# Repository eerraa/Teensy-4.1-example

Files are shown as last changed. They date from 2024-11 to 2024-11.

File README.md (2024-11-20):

# Teensy 4.1 Kicad example project
Kicad files to make a custom Teensy 4.1, based on the official Teensy schematics, but exposing all pins for testing. All the 55 pins except D41 are brought out for testing. I'm using a USB Type C receptacle rather than USB Micro / A connectors. Don't forget that you'll need to buy the MKL02Z32VFG4 from PJRC for this to work. Also - be sure to scroll down on the MKL02Z32VFG4 page. There are [lots of important information there](https://www.pjrc.com/store/ic_mkl02_t4.html) on power sequencing and layout.

## Know bugs
This version is tested and works, but the MAX1562 that I used for the USB switch has inverted polarity from what is expected. You can get around this by using the alternate part MAX1563, or something else. Only reason I went with this 4A chip is the parts shortage.

I just removed the chip and soldered bodge-wires to bypass it. This also works, but I guess it then lacks protection. I've tested with keyboard & mouse.

## Features

The board includes the required parts

- MIMXRT1062DVJ6B (Arm Cortex M7 @ 600 Mhz)
- MKL02Z32VFG4 (must be purchased from PJRC)
- W25Q64JVXGIM (8Mb spi Flash)

Optional parts (not in PJRC's design)

- [USB Type C](https://github.com/jenschr/USB-C-Connectors) for power & debug
- USB Type C host port with MAX1562 for power control
- 2.54mm pin header connections for all pins but D41
- JTAG pins broken out (not tested, but there)

Not included (from PJRC's design)
- Extra SpiFlash or PSRAM
- Ethernet

Note: the schematic symbol for the IMXRT1062 chip is really clumsy and makes the schematic more complex than required, but that's what you get if you use SamacSys Library Loader rather than making the symbol yourself.

## Picture
Here's a picture of the boards when I soldered them:



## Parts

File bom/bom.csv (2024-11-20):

Designator | Footprint | Quantity | Value | LCSC Part #
C1, C10, C13, C17, C2, C22, C23, C25, C4, C8 | 603 | 10 | 0.22uf | C21120
C11, C18, C9 | 805 | 3 | 10uf | C15850
C12, C19, C24, C26, C6 | 603 | 5 | 4.7uf | C19666
C14, C15 | 603 | 2 | 10pf | C1634
C16, C21 | 603 | 2 | 9pf | C430713
C20, C5 | 603 | 2 | 10nf | C57112
C3, C7 | 603 | 2 | 2.2uf | C23630
D1 | SOT-143 | 1 | SP0503BAHT | C7074
D2, D4 | 402 | 2 | LED | C20613596
D3 | SOT-23 | 1 | BAT54C | C37704
F1 | 805 | 1 | Fuse | C5220829
FB1, FB2 | 805 | 2 | Ferrite_Bead | C454098
IC1 | BGA196C80P14X14_1200X1200X152 | 1 | MIMXRT1062DVJ6B | C3216699
J1, J2 | Hirose_FH12-20S-0.5SH_1x20-1MP_P0.50mm_Horizontal | 2 | Conn_01x20 | C596730
J3 | PinHeader_1x03_P2.54mm_Vertical | 1 | Conn_01x03_Male
L1 | 805 | 1 | 4.7uH | C86090
NCP1 | DFN-6-1EP_3x3mm_P0.95mm_EP1.7x2.6mm | 1 | OnSemi NCP692, fixed version | C145519
PROG1 | KMR241GLFS | 1 | SW_Push | C221682
Q1 | SOT-23 | 1 | Q_PMOS_GDS_DMP3125L | C459542
R1, R2 | 603 | 2 | 5.1k | C23186
R3, R4, R9 | 603 | 3 | 100k | C25803
R5 | 603 | 1 | 1M | C22935
R6, R8 | 402 | 2 | 1k | C11702
R7 | 603 | 1 | 2.2M | C22938
SWD1 | PinHeader_1x07_P1.27mm_Vertical | 1 | SWD
TP1, TP2, TP3, TP4, TP5, TP6, TP7 | TestPoint_Pad_D1.0mm | 7 | TestPoint
U1 | XSON8_4x4mm | 1 | W25Q64JVXGIM
U2 | QFN-16-1EP_3x3mm_P0.5mm_EP1.8x1.8mm | 1 | MKL02Z32VFG4
USB_UFP1 | USB_C_Receptacle_Hroparts_TYPE-C-31-M-12 | 1 | USB_C_Receptacle_USB2.0 | C165948
Y1 | Crystal_SMD_Abracon_ABM3B-4Pin_5.0x3.2mm | 1 | Crystal_GND23 | C112587
Y2 | Crystal_SMD_2012-2Pin_2.0x1.2mm | 1 | Crystal | C510776

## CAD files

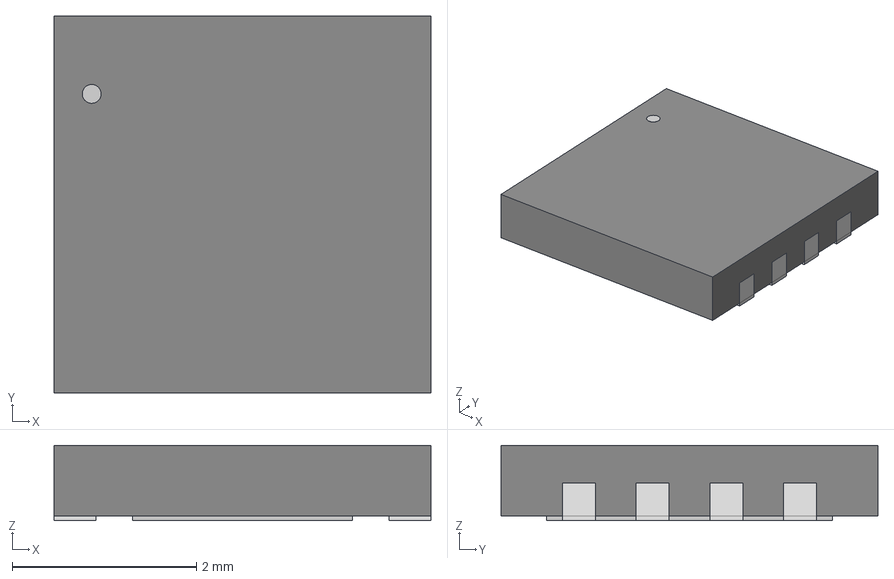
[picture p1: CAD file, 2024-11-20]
3d/DFN_XGIQTR_WIN.step
4.09 x 4.09 x 0.815 mm

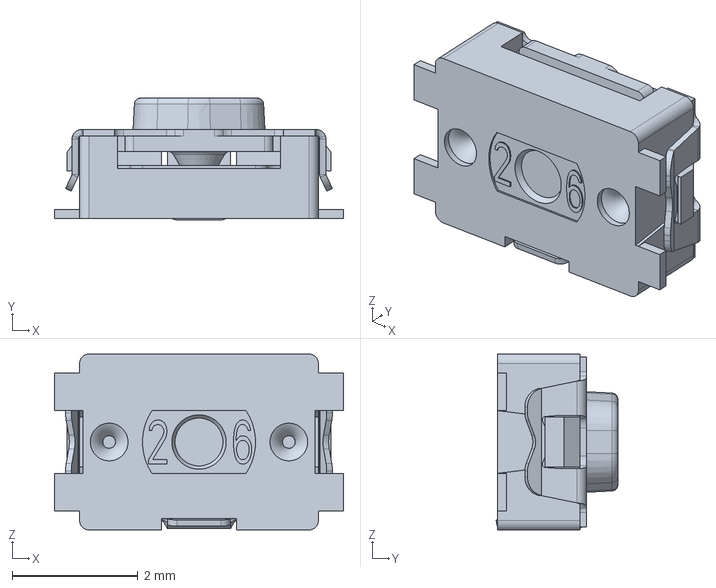
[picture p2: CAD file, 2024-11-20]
3d/KMR241GLFS.stp
4.60 x 1.94 x 2.80 mm

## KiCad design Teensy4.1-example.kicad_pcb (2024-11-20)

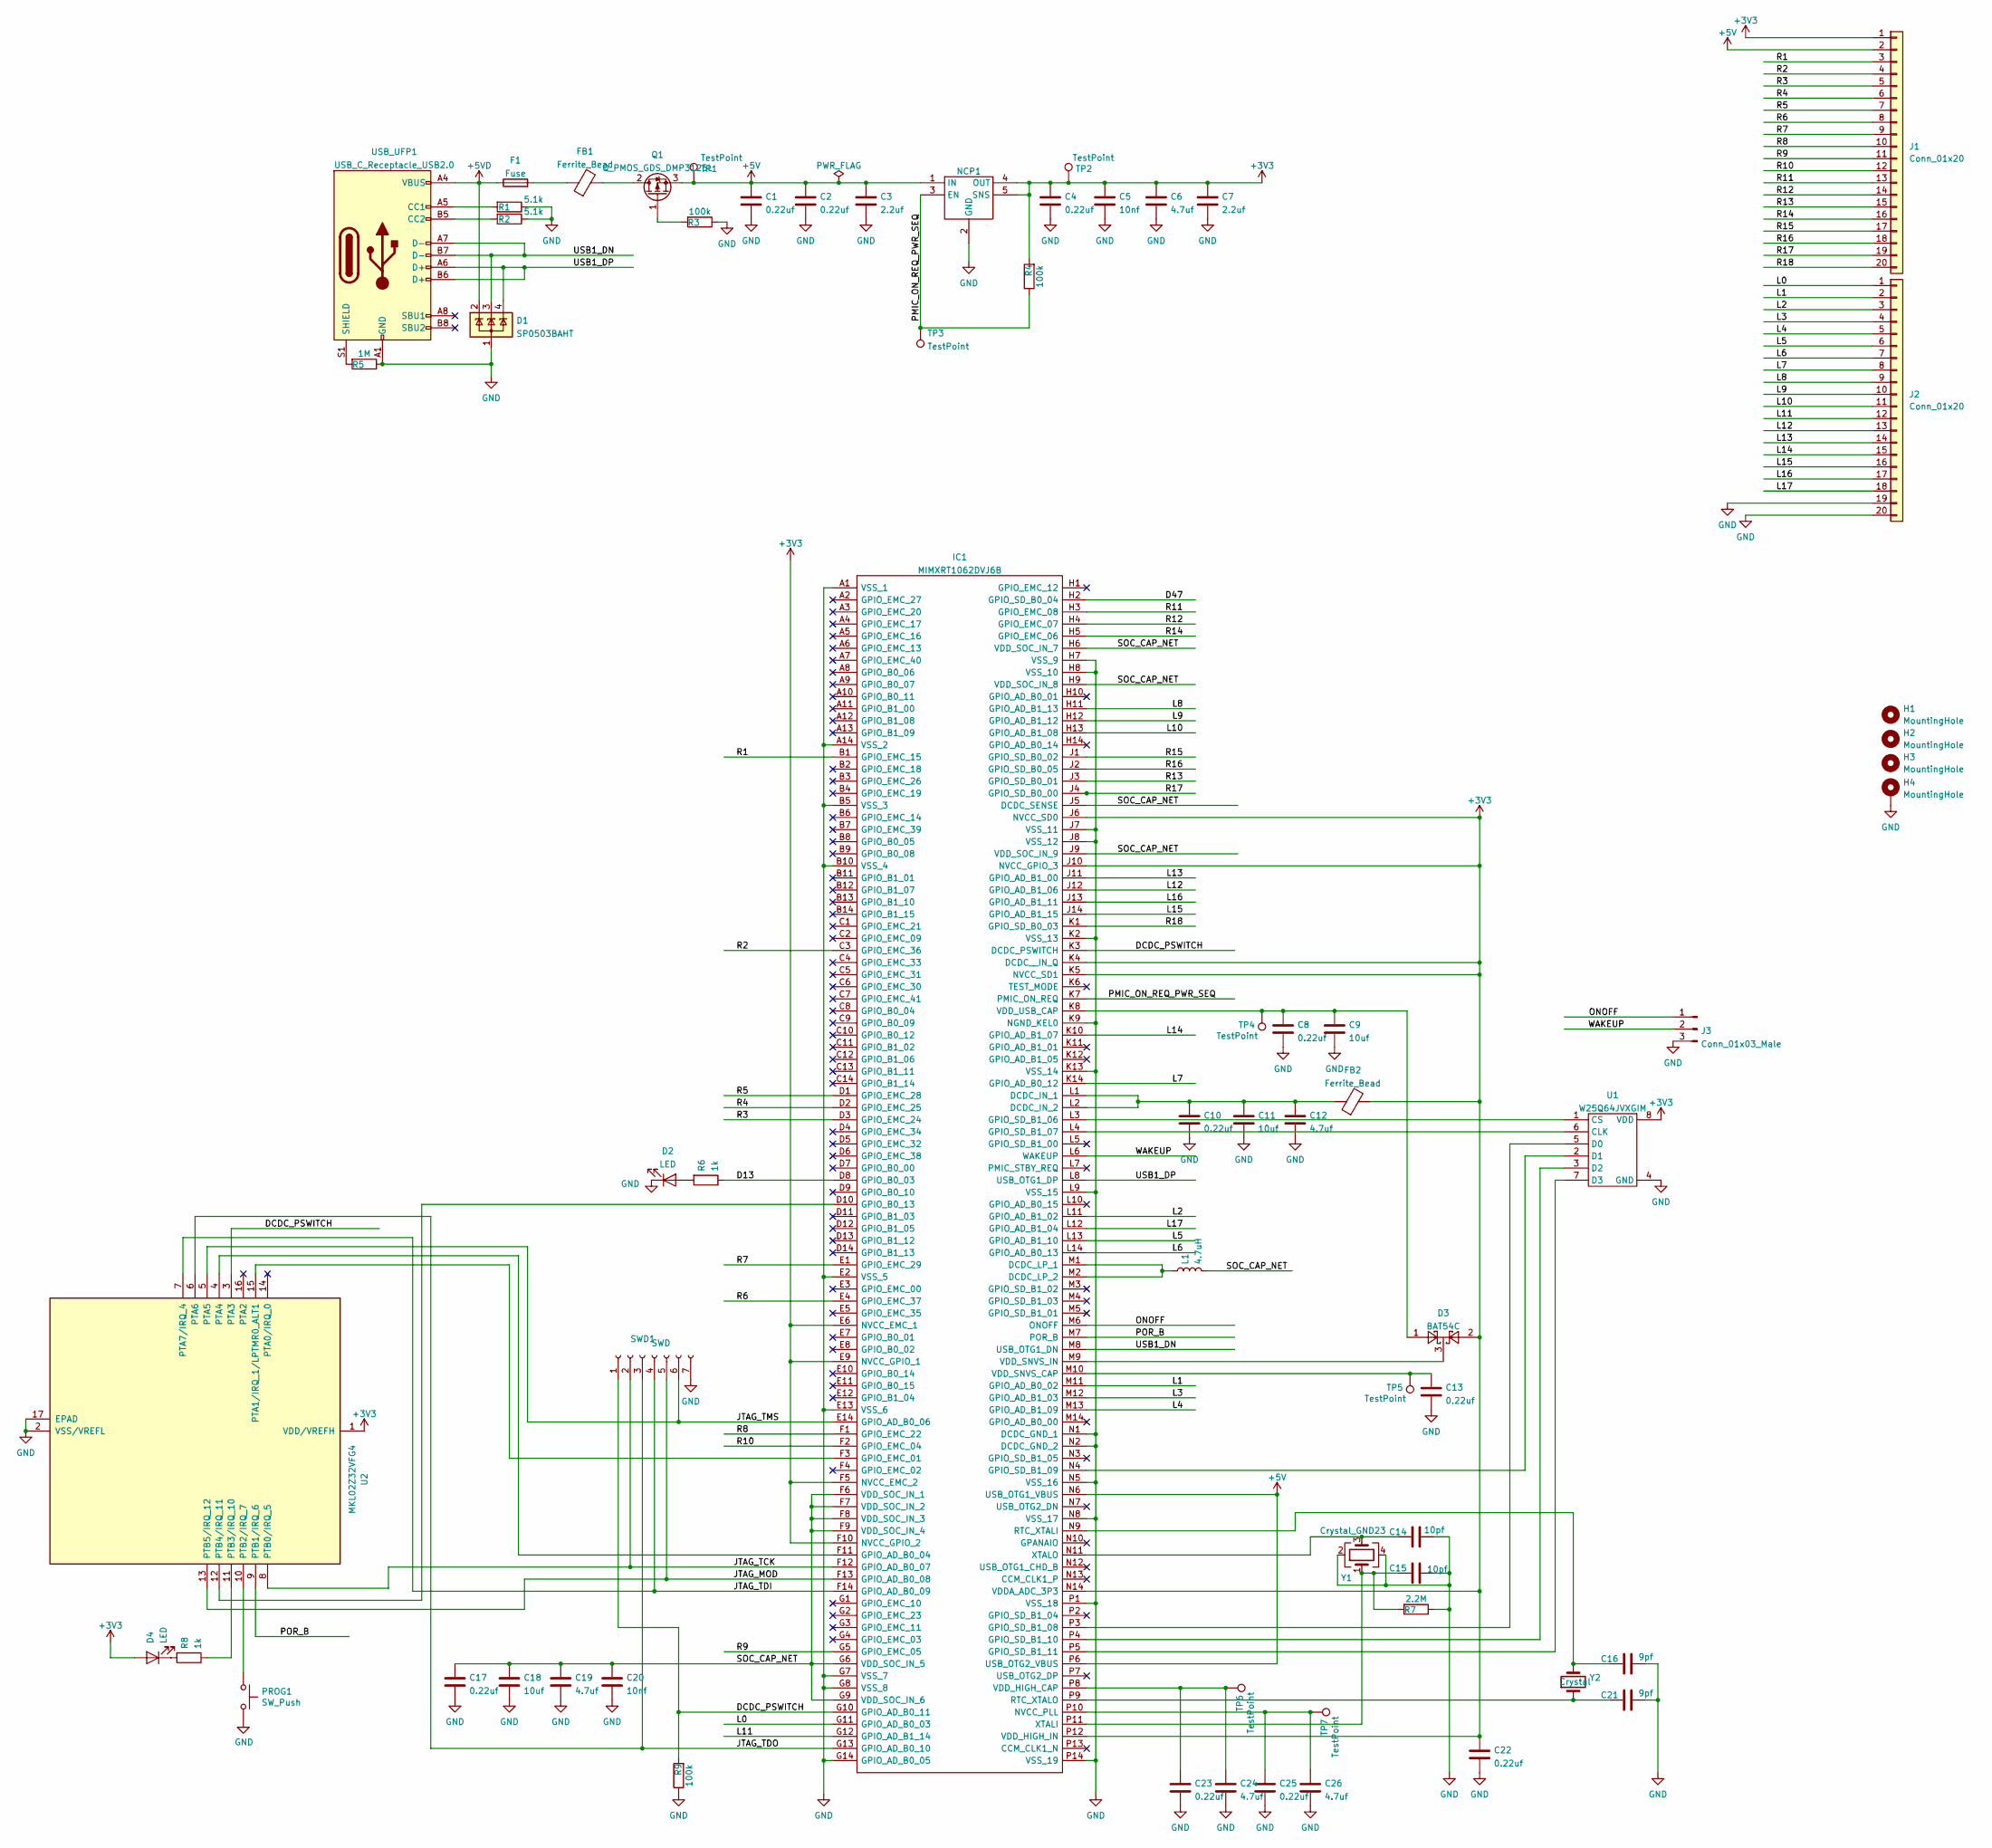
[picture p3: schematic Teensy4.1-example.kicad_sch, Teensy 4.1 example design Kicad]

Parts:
C1, C2, C4, C8, C10, C13, C17, C22, C23, C25: 0.22uf; C_0603_1608Metric; MPN CC0603KRX7R6BB224
C3, C7: 2.2uf; C_0603_1608Metric; MPN CL10B225KP8NNNC
C5, C20: 10nf; C_0603_1608Metric; MPN 0603B103K160CT
C6, C12, C19, C24, C26: 4.7uf; C_0603_1608Metric; MPN CL10B475KQ8NQNC
C9, C11, C18: 10uf; C_0805_2012Metric; MPN GRM21BR71A106KA73K
C14, C15: 10pf; C_0603_1608Metric; MPN CC0603KRX7R6BB224
C16, C21: 9pf; C_0603_1608Metric; MPN GRM1885C1H9R0DA01D
D1: SP0503BAHT; SOT-143
D2, D4: LED; LED_0402_1005Metric
D3: BAT54C; SOT-23
F1: Fuse; R_0805_2012Metric; MPN 0ZCK0050FF2E
FB1, FB2: Ferrite_Bead; R_0805_2012Metric; MPN FBMH2012HM121-T‎
H1, H2, H3, H4: MountingHole; MountingHole_2.7mm_M2.5_DIN965_Pad_TopBottom
IC1: MIMXRT1062DVJ6B; BGA196C80P14X14_1200X1200X152; Mouser Part Number 771-MIMXRT1062DVJ6B
J1, J2: Conn_01x20; Hirose_FH12-20S-0.5SH_1x20-1MP_P0.50mm_Horizontal
J3: Conn_01x03_Male; PinHeader_1x03_P2.54mm_Vertical
L1: 4.7uH; C_0805_2012Metric; MPN LQM21PN4R7MGRD
NCP1: OnSemi NCP692, fixed version; DFN-6-1EP_3x3mm_P0.95mm_EP1.7x2.6mm; MPN NCP692MN33T2G
PROG1: SW_Push; KMR241GLFS; MPN KMR241GLFS
Q1: Q_PMOS_GDS_DMP3125L; SOT-23
R1, R2: 5.1k; R_0603_1608Metric; MPN RC0603FR-075K1L
R3, R4, R9: 100k; R_0603_1608Metric
R5: 1M; R_0603_1608Metric
R6, R8: 1k; R_0402_1005Metric
R7: 2.2M; R_0603_1608Metric
SWD1: SWD; PinHeader_1x07_P1.27mm_Vertical
TP1, TP2, TP3, TP4, TP5, TP6, TP7: TestPoint; TestPoint_Pad_D1.0mm
U1: W25Q64JVXGIM; XSON8_4x4mm
U2: MKL02Z32VFG4; QFN-16-1EP_3x3mm_P0.5mm_EP1.8x1.8mm; MPN Custom firmware part
USB_UFP1: USB_C_Receptacle_USB2.0; USB_C_Receptacle_Hroparts_TYPE-C-31-M-12
Y1: Crystal_GND23; Crystal_SMD_Abracon_ABM3B-4Pin_5.0x3.2mm
Y2: Crystal; Crystal_SMD_2012-2Pin_2.0x1.2mm; MPN ABS06-32.768KHZ-9-1-T

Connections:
+3V3: C4.1, C5.1, C6.1, C7.1, C22.1, D3.2, D4.2 (A), FB2.2, IC1.E6 (NVCC_EMC_1), IC1.E9 (NVCC_GPIO_1), IC1.F5 (NVCC_EMC_2), IC1.F10 (NVCC_GPIO_2), IC1.J6 (NVCC_SD0), IC1.J10 (NVCC_GPIO_3), IC1.K4 (DCDC__IN_Q), IC1.K5 (NVCC_SD1), IC1.N14 (VDDA_ADC_3P3), IC1.P12 (VDD_HIGH_IN), J1.1, NCP1.4 (OUT), NCP1.5 (SNS), R4.2, TP2.1, U1.8 (VDD), U2.1 (VDD/VREFH)
+5V: C1.1, C2.1, C3.1, IC1.N6 (USB_OTG1_VBUS), IC1.P6 (USB_OTG2_VBUS), J1.2, NCP1.1 (IN), NCP1.6 (IN), Q1.3 (S), TP1.1
+5VD: D1.2 (K), F1.1, USB_UFP1.A4 (VBUS), USB_UFP1.A9 (VBUS), USB_UFP1.B4 (VBUS), USB_UFP1.B9 (VBUS)
/D13: IC1.D8 (GPIO_B0_03), R6.1
/D47: IC1.H2 (GPIO_SD_B0_04)
/DCDC_PSWITCH: IC1.G10 (GPIO_AD_B0_11), IC1.K3 (DCDC_PSWITCH), R9.2, SWD1.1, U2.3 (PTA3)
/JTAG_MOD: IC1.F13 (GPIO_AD_B0_08), SWD1.5, U2.13 (PTB5/IRQ_12)
/JTAG_TCK: IC1.F12 (GPIO_AD_B0_07), SWD1.2, U2.8 (PTB0/IRQ_5)
/JTAG_TDI: IC1.F14 (GPIO_AD_B0_09), SWD1.4, U2.7 (PTA7/IRQ_4)
/JTAG_TDO: IC1.G13 (GPIO_AD_B0_10), SWD1.3, U2.6 (PTA6)
/JTAG_TMS: IC1.E14 (GPIO_AD_B0_06), SWD1.6, U2.5 (PTA5)
/L0: IC1.G11 (GPIO_AD_B0_03), J2.1
/L1: IC1.M11 (GPIO_AD_B0_02), J2.2
/L2: IC1.L11 (GPIO_AD_B1_02), J2.3
/L3: IC1.M12 (GPIO_AD_B1_03), J2.4
/L4: IC1.M13 (GPIO_AD_B1_09), J2.5
/L5: IC1.L13 (GPIO_AD_B1_10), J2.6
/L6: IC1.L14 (GPIO_AD_B0_13), J2.7
/L7: IC1.K14 (GPIO_AD_B0_12), J2.8
/L8: IC1.H11 (GPIO_AD_B1_13), J2.9
/L9: IC1.H12 (GPIO_AD_B1_12), J2.10
/L10: IC1.H13 (GPIO_AD_B1_08), J2.11
/L11: IC1.G12 (GPIO_AD_B1_14), J2.12
/L12: IC1.J12 (GPIO_AD_B1_06), J2.13
/L13: IC1.J11 (GPIO_AD_B1_00), J2.14
/L14: IC1.K10 (GPIO_AD_B1_07), J2.15
/L15: IC1.J14 (GPIO_AD_B1_15), J2.16
/L16: IC1.J13 (GPIO_AD_B1_11), J2.17
/L17: IC1.L12 (GPIO_AD_B1_04), J2.18
/ONOFF: IC1.M6 (ONOFF), J3.1
/PMIC_ON_REQ_PWR_SEQ: IC1.K7 (PMIC_ON_REQ), NCP1.3 (EN), R4.1, TP3.1
/POR_B: IC1.M7 (POR_B), U2.9 (PTB1/IRQ_6)
/R1: IC1.B1 (GPIO_EMC_15), J1.3
/R2: IC1.C3 (GPIO_EMC_36), J1.4
/R3: IC1.D3 (GPIO_EMC_24), J1.5
/R4: IC1.D2 (GPIO_EMC_25), J1.6
/R5: IC1.D1 (GPIO_EMC_28), J1.7
/R6: IC1.E4 (GPIO_EMC_37), J1.8
/R7: IC1.E1 (GPIO_EMC_29), J1.9
/R8: IC1.F1 (GPIO_EMC_22), J1.10
/R9: IC1.G5 (GPIO_EMC_05), J1.11
/R10: IC1.F2 (GPIO_EMC_04), J1.12
/R11: IC1.H3 (GPIO_EMC_08), J1.13
/R12: IC1.H4 (GPIO_EMC_07), J1.14
/R13: IC1.J3 (GPIO_SD_B0_01), J1.15
/R14: IC1.H5 (GPIO_EMC_06), J1.16
/R15: IC1.J1 (GPIO_SD_B0_02), J1.17
/R16: IC1.J2 (GPIO_SD_B0_05), J1.18
/R17: IC1.J4 (GPIO_SD_B0_00), J1.19
/R18: IC1.K1 (GPIO_SD_B0_03), J1.20
/SOC_CAP_NET: C17.1, C18.1, C19.1, C20.1, IC1.F6 (VDD_SOC_IN_1), IC1.F7 (VDD_SOC_IN_2), IC1.F8 (VDD_SOC_IN_3), IC1.F9 (VDD_SOC_IN_4), IC1.G6 (VDD_SOC_IN_5), IC1.G9 (VDD_SOC_IN_6), IC1.H6 (VDD_SOC_IN_7), IC1.H9 (VDD_SOC_IN_8), IC1.J5 (DCDC_SENSE), IC1.J9 (VDD_SOC_IN_9), L1.2
/USB1_DN: D1.3 (K), IC1.M8 (USB_OTG1_DN), USB_UFP1.A7 (D-), USB_UFP1.B7 (D-)
/USB1_DP: D1.4 (K), IC1.L8 (USB_OTG1_DP), USB_UFP1.A6 (D+), USB_UFP1.B6 (D+)
/WAKEUP: IC1.L6 (WAKEUP), J3.2
GND: C1.2, C2.2, C3.2, C4.2, C5.2, C6.2, C7.2, C8.2, C9.2, C10.2, C11.2, C12.2, C13.2, C14.2, C15.2, C16.2, C17.2, C18.2, C19.2, C20.2, C21.2, C22.2, C23.2, C24.2, C25.2, C26.2, D1.1 (A), D2.1 (K), H4.1, IC1.A1 (VSS_1), IC1.A14 (VSS_2), IC1.B5 (VSS_3), IC1.B10 (VSS_4), IC1.E2 (VSS_5), IC1.E13 (VSS_6), IC1.G7 (VSS_7), IC1.G8 (VSS_8), IC1.G14 (GPIO_AD_B0_05), IC1.H7 (VSS_9), IC1.H8 (VSS_10), IC1.J7 (VSS_11), IC1.J8 (VSS_12), IC1.K2 (VSS_13), IC1.K9 (NGND_KEL0), IC1.K13 (VSS_14), IC1.L9 (VSS_15), IC1.N1 (DCDC_GND_1), IC1.N2 (DCDC_GND_2), IC1.N5 (VSS_16), IC1.N8 (VSS_17), IC1.P1 (VSS_18), IC1.P14 (VSS_19), J2.19, J2.20, J3.3, NCP1.2 (GND), NCP1.7 (GND), PROG1.2, R1.1, R2.1, R3.1, R5.1, R7.1, R9.1, SWD1.7, U1.4 (GND), U2.2 (VSS/VREFL), U2.17 (EPAD), USB_UFP1.A1 (GND), USB_UFP1.A12 (GND), USB_UFP1.B1 (GND), USB_UFP1.B12 (GND), Y1.2, Y1.4
unnamed: D2.2 (A), R6.2
unnamed: D4.1 (K), R8.2
unnamed: F1.2, FB1.1
unnamed: C10.1, C11.1, C12.1, FB2.1, IC1.L1 (DCDC_IN_1), IC1.L2 (DCDC_IN_2)
unnamed: IC1.M1 (DCDC_LP_1), IC1.M2 (DCDC_LP_2), L1.1
unnamed: IC1.F11 (GPIO_AD_B0_04), U2.4 (PTA4)
unnamed: IC1.D10 (GPIO_B0_13), U2.12 (PTB4/IRQ_11)
unnamed: IC1.F3 (GPIO_EMC_01), U2.15 (PTA1/IRQ_1/LPTMR0_ALT1)
unnamed: IC1.L3 (GPIO_SD_B1_06), U1.1 (CS)
unnamed: IC1.L4 (GPIO_SD_B1_07), U1.6 (CLK)
unnamed: IC1.P3 (GPIO_SD_B1_08), U1.5 (D0)
unnamed: IC1.N4 (GPIO_SD_B1_09), U1.2 (D1)
unnamed: IC1.P4 (GPIO_SD_B1_10), U1.3 (D2)
unnamed: IC1.P5 (GPIO_SD_B1_11), U1.7 (D3)
unnamed: C25.1, C26.1, IC1.P10 (NVCC_PLL), TP7.1
unnamed: C16.1, IC1.N9 (RTC_XTALI), Y2.2
unnamed: C21.1, IC1.P9 (RTC_XTALO), Y2.1
unnamed: C23.1, C24.1, IC1.P8 (VDD_HIGH_CAP), TP6.1
unnamed: C13.1, IC1.M10 (VDD_SNVS_CAP), TP5.1
unnamed: D3.3, IC1.M9 (VDD_SNVS_IN)
unnamed: C8.1, C9.1, D3.1, IC1.K8 (VDD_USB_CAP), TP4.1
unnamed: C15.1, IC1.P11 (XTALI), R7.2, Y1.1
unnamed: C14.1, IC1.N11 (XTALO), Y1.3
unnamed: FB1.2, Q1.2 (D)
unnamed: Q1.1 (G), R3.2
unnamed: PROG1.1, U2.10 (PTB2/IRQ_7)
unnamed: R8.1, U2.11 (PTB3/IRQ_10)
unnamed: R1.2, USB_UFP1.A5 (CC1)
unnamed: R2.2, USB_UFP1.B5 (CC2)
unnamed: R5.2, USB_UFP1.S1 (SHIELD)

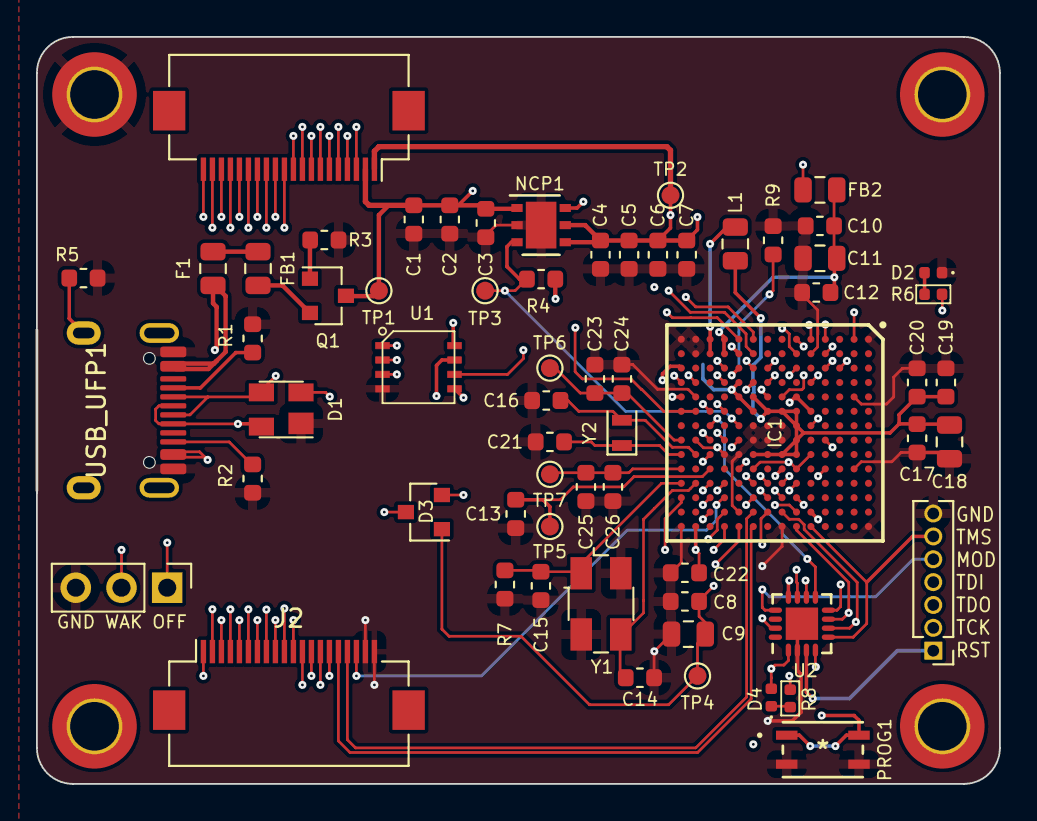
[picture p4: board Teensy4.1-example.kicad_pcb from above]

Board: 4 copper layers, 53.5 x 41.5 mm, 67 parts (0 on the bottom side), 84 nets.

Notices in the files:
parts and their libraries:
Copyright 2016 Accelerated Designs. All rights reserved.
